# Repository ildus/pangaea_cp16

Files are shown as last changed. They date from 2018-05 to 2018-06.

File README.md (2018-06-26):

# Cabinet simulator (on impulse responses) based on AMT Pangaea CP-16

Contains schematic and pcb. Based on debugging board of CP16.

## Basic components.

* Pangaea CP-16
* NE5532D (3pcs) operational amplifiers.
* 0 Ohm 2512 SMD resistors
* 1206 SMD resistors
* 0805 SMD capacitors
* Electrolytic capacitors
* 15pin (pangaea), 4pin (pangaea control), 6pin (double potenciometer), and 2pcs of 2pin headers.
* 3pcs of 6.3mm audio jacks.
* 1pic of USB connector.

For the values of resistors and capacitors check the schematic.

## Pangaea CP-16 (copied from AMT website).

AMT Pangaea CP-16 module lets you to emulate any Guitar Cabinet sounding by loading appropriate
Guitar Cabinets’ Impulse Responses (IRs).

You can load up to 16 different Guitar Cabinets’ IRs in the module’s memory and choose the desired
one in the right moment. You can load IRs in the CP-16 memory and control their parameters via USB.

pangaea

## Important note

As you can see on the image above, the pin header soldered on the side opposite to side with capacitor, that's not optimal and takes twice as much height. The PCB is designed to use with CP16 where pin header is soldered on the side of capacitor so the whole pcb can be put to usual aluminum case.

## PCB

up
down

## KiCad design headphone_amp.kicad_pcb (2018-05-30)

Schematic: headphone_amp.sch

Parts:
C1, C6, C13, C22, C24, C29, C30: 100n; C_0805_2012Metric
C2, C3, C4, C5: 47u; CP_Radial_D4.0mm_P2.00mm
C9, C10: 4.7u; C_0805_2012Metric
C12, C25, C26: 22p; C_0805_2012Metric
C14, C15: 470p; C_0805_2012Metric
C16, C17, C19: 1.2n; C_0805_2012Metric
C18: 0.22u; C_0805_2012Metric
C20, C21: 100p; C_0805_2012Metric
C27, C28: 220u; CP_Radial_D6.3mm_P2.50mm
D1: red; PinSocket_1x02_P2.00mm_Vertical
D2: BAV99; SOT-23
J1: btn; PinSocket_1x02_P2.54mm_Vertical
J2: AUX_IN; Jack6P
J3: IN; Jack6P
J4: pangea_cp16; PinSocket_1x15_P2.54mm_Vertical
J5: USB_A
J6: OUT; Jack6P
J7: PWR; PinSocket_1x02_P2.54mm_Vertical
J10: Conn_01x04; PinSocket_1x04_P2.54mm_Vertical
R1, R23: 68K; R_1206_3216Metric
R2, R30, R31, R36, R38, R39, R40: 0; R_2512_6332Metric
R5, R8, R9, R10, R11, R12, R26, R27, R34, R35: 100k; R_1206_3216Metric
R7: 2m; R_1206_3216Metric
R13: 150k; R_1206_3216Metric
R14, R15, R16, R17, R19, R20, R21, R22: 10k; R_1206_3216Metric
R18: 100; R_1206_3216Metric
R24, R25: 390k; R_1206_3216Metric
R28, R29: 10; R_1206_3216Metric
R32, R33: 2k; R_1206_3216Metric
R37: 3k; R_1206_3216Metric
RV2: B50K; PinSocket_1x06_P2.54mm_Vertical
U1, U3, U4: NE5532; SO-8_5.3x6.2mm_P1.27mm

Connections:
+4V: R9.2, R11.1, R12.1, R21.1, R22.1, R39.1, R39.2, U1.1, U1.2 (-)
+9V: C1.1, C2.1, C13.1, C22.2, C24.1, D1.2, D2.2, J4.15, J7.2, R2.1, R2.2, R5.2, R30.1, R30.2, R31.1, R31.2, R36.1, R36.2, U1.8 (V+), U3.8 (V+), U4.8 (V+)
/ain: J4.4, R38.1
/aoutl: C9.2, J4.2
/aoutr: C10.2, J4.1
/aux_l: C25.2, R24.2, R26.1, R35.1, U4.2 (-)
/aux_r: C26.2, R25.2, R27.1, R34.1, U4.6 (-)
/outl: J6.1, R28.1
/outr: J6.2, R29.1
/ps1: J4.13, J10.1
/ps2: J4.12, J10.2
/ps3: J4.11, J10.3
/ps4: J4.10, J10.4
Earth: J1.2, J7.1
GND: C1.2, C2.2, C3.2, C4.2, C5.2, C13.2, C14.2, C15.2, C19.2, C20.2, C21.2, C22.1, C24.2, D2.1, J1.1, J2.3, J2.4, J2.5, J3.3, J3.4, J4.3, J4.5, J4.14, J5.4, J5.5, J6.3, R7.2, R8.2, R32.1, R33.1, R37.2, U1.4 (V-), U3.4 (V-), U4.4 (V-)
unnamed: C3.1, RV2.6
unnamed: C4.1, R5.1, R8.1, U1.3 (+)
unnamed: C5.1, RV2.3
unnamed: C6.1, R10.2
unnamed: C6.2, J3.1, R7.1
unnamed: C9.1, R11.2, R14.1
unnamed: C10.1, R12.2, R15.1
unnamed: C12.1, C18.1, R13.1, U1.7
unnamed: C12.2, D2.3, R10.1, R13.2, U1.6 (-)
unnamed: C14.1, R14.2, R16.1
unnamed: C15.1, R15.2, R17.1
unnamed: C16.1, R1.1, U3.1, U3.2 (-)
unnamed: C16.2, R16.2, R19.1
unnamed: C17.1, R40.1, U3.6 (-), U3.7
unnamed: C17.2, R17.2, R20.1
unnamed: C18.2, R18.1
unnamed: C19.1, R18.2, R38.2
unnamed: C20.1, R19.2, U3.3 (+)
unnamed: C21.1, R20.2, U3.5 (+)
unnamed: C25.1, C27.1, R24.1, U4.1
unnamed: C26.1, C28.1, R25.1, U4.7
unnamed: C27.2, R28.2
unnamed: C28.2, R29.2
unnamed: C29.1, R35.2
unnamed: C29.2, J2.1, R32.2
unnamed: C30.1, R34.2
unnamed: C30.2, J2.2, R33.2
unnamed: D1.1, R37.1
unnamed: J4.6, J5.3
unnamed: J4.7, J5.2
unnamed: J4.8, J5.1
unnamed: R1.2, RV2.1
unnamed: R9.1, U1.5 (+)
unnamed: R21.2, U4.3 (+)
unnamed: R22.2, U4.5 (+)
unnamed: R23.1, R40.2
unnamed: R23.2, RV2.4
unnamed: R26.2, RV2.2
unnamed: R27.2, RV2.5

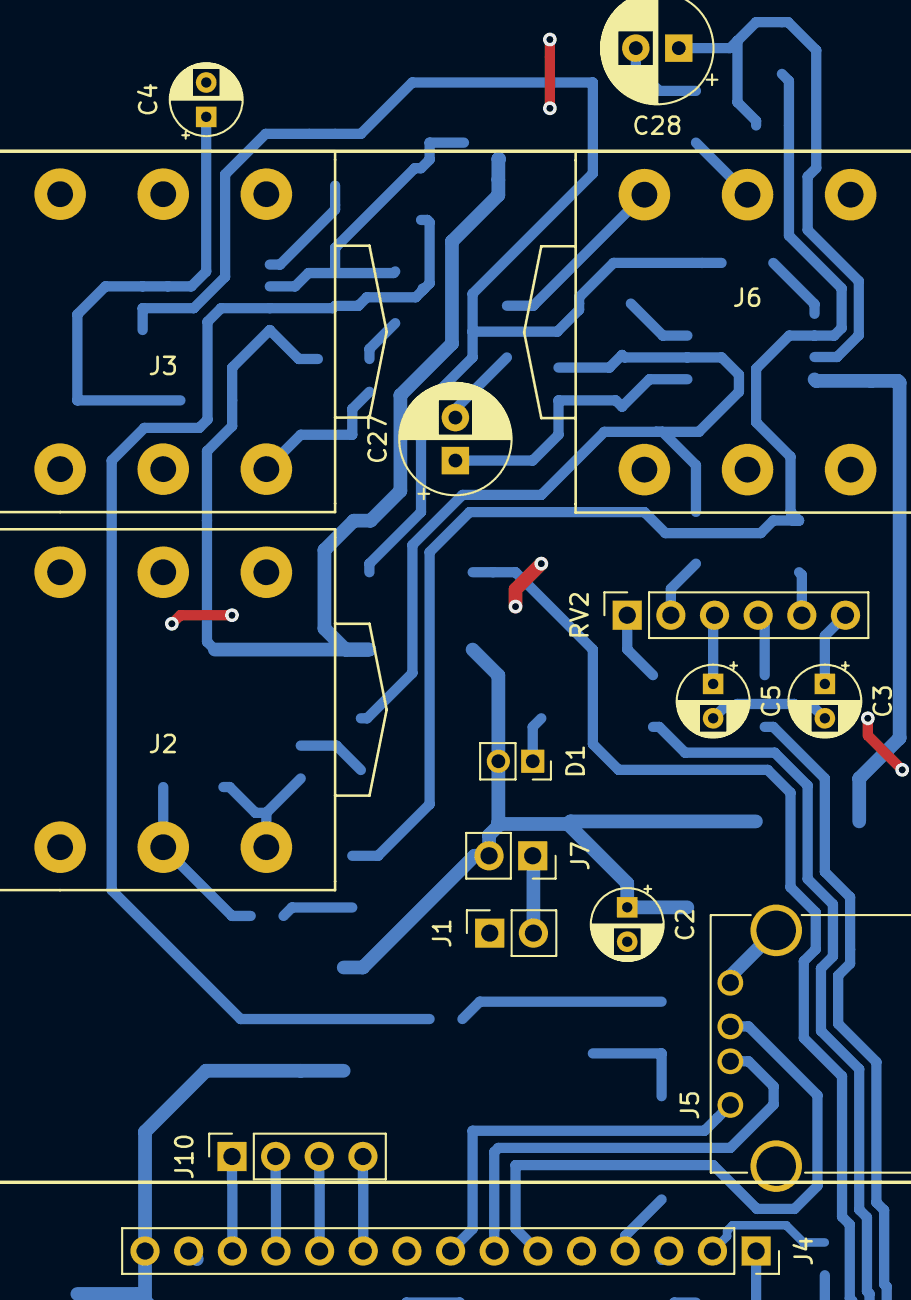
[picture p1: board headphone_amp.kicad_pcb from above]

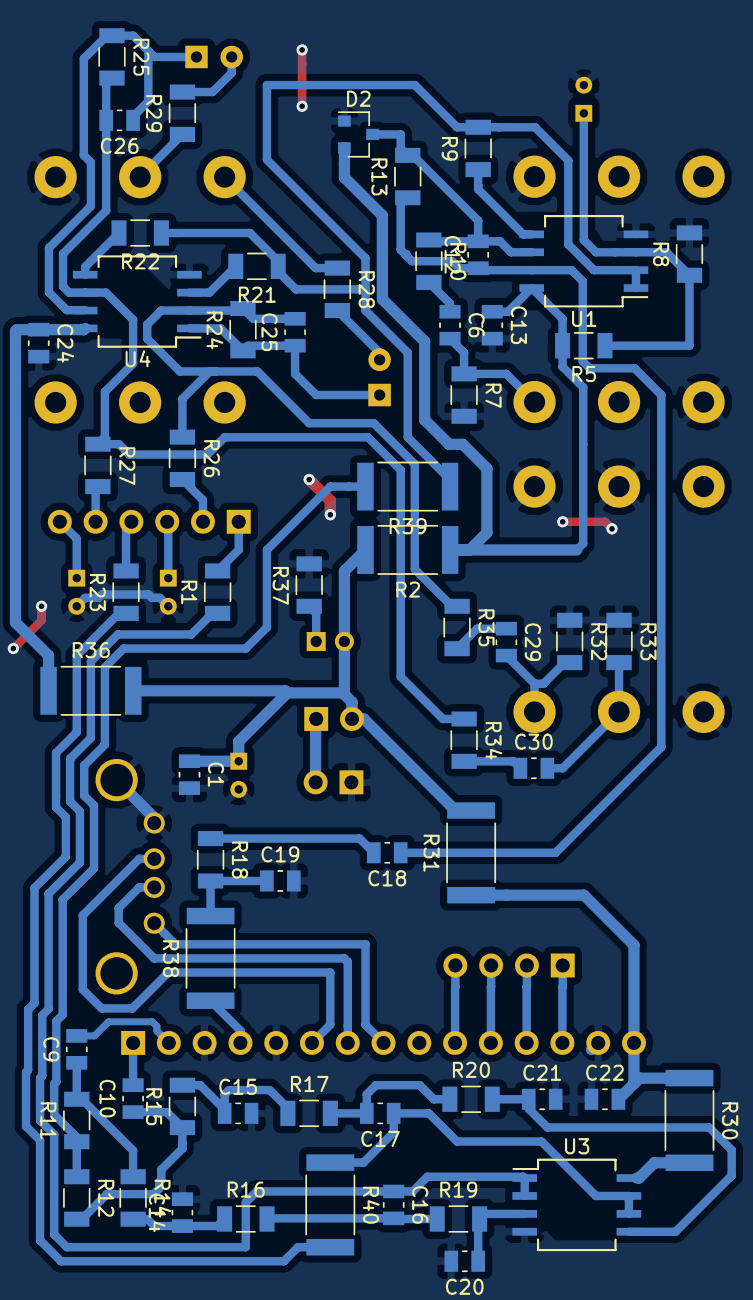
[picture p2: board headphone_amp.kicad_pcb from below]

Board: 2 copper layers, 77 parts (61 on the bottom side), 54 nets.
